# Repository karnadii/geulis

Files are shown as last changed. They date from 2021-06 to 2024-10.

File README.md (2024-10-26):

# Geulis
Wireless alice layout keyboard
# Images
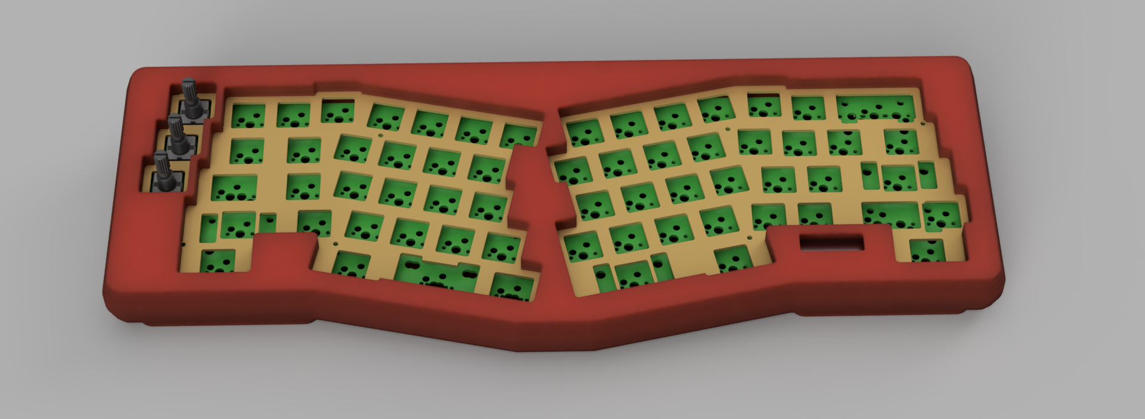
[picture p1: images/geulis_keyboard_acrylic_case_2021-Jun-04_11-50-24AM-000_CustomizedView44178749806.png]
PCB Front View


# Firmware
[https://github.com/karnadii/geulis_config_module](https://github.com/karnadii/geulis_config_module)

NOTE: My keyboard case is terrible. Make your own case or use someone else's. The RGB drains a lot of battery, but if you cut the power trace to the RGB, the battery life is amazing, thanks to ZMK. I haven't charged my keyboard in over half a year, and it still has more than 50% battery left.

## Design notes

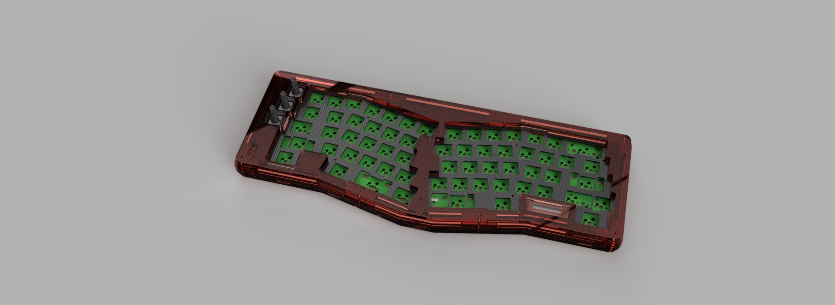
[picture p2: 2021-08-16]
images/geulis_acrylic_case_v3_screw_2021-Jul-15_01-08-26AM-000_CustomizedView15097228685.png

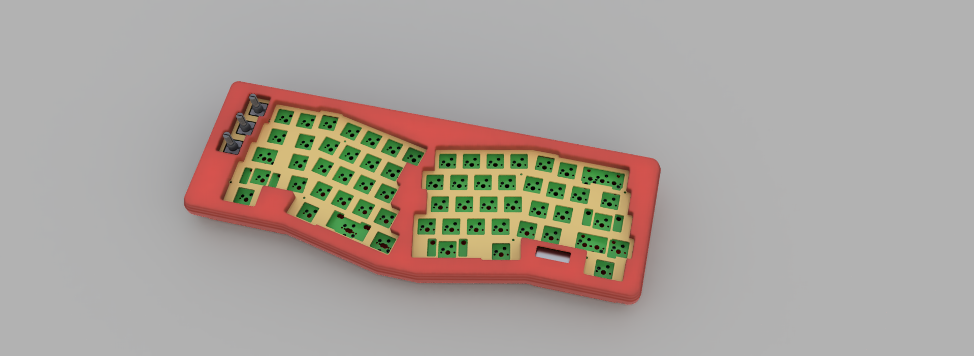
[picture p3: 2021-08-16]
images/c8df9fd2-e070-493f-910b-0edc783d997d.PNG

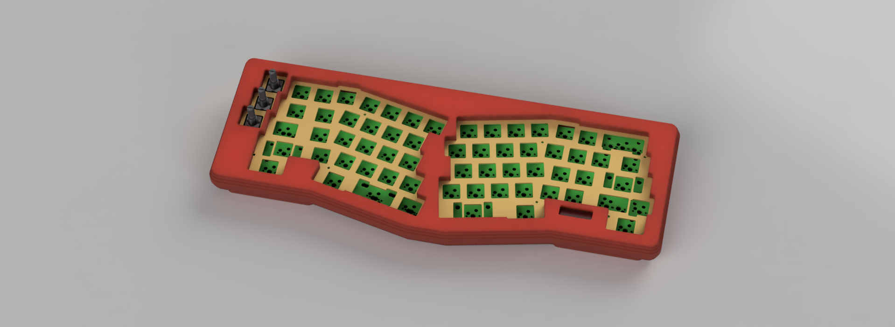
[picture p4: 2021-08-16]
images/geulis_keyboard_acrylic_case_2021-Jun-03_07-44-22PM-000_CustomizedView18685608333.png

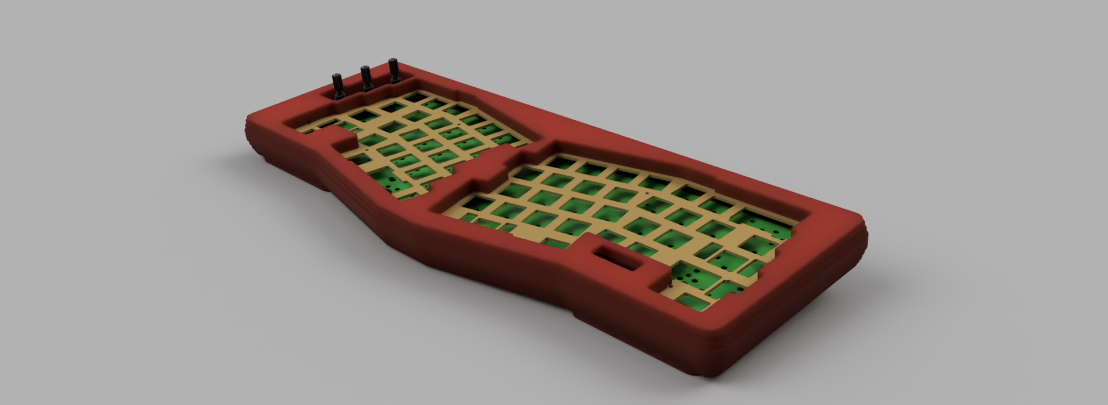
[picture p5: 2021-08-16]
images/geulis_keyboard_acrylic_case_2021-Jun-03_07-30-29PM-000_CustomizedView2518468134.png

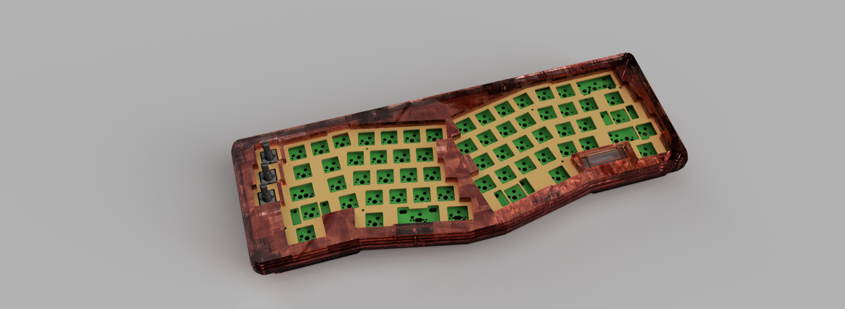
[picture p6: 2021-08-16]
images/6f7de3ee-63c1-44c7-aa9e-37ba1ee566a7.PNG

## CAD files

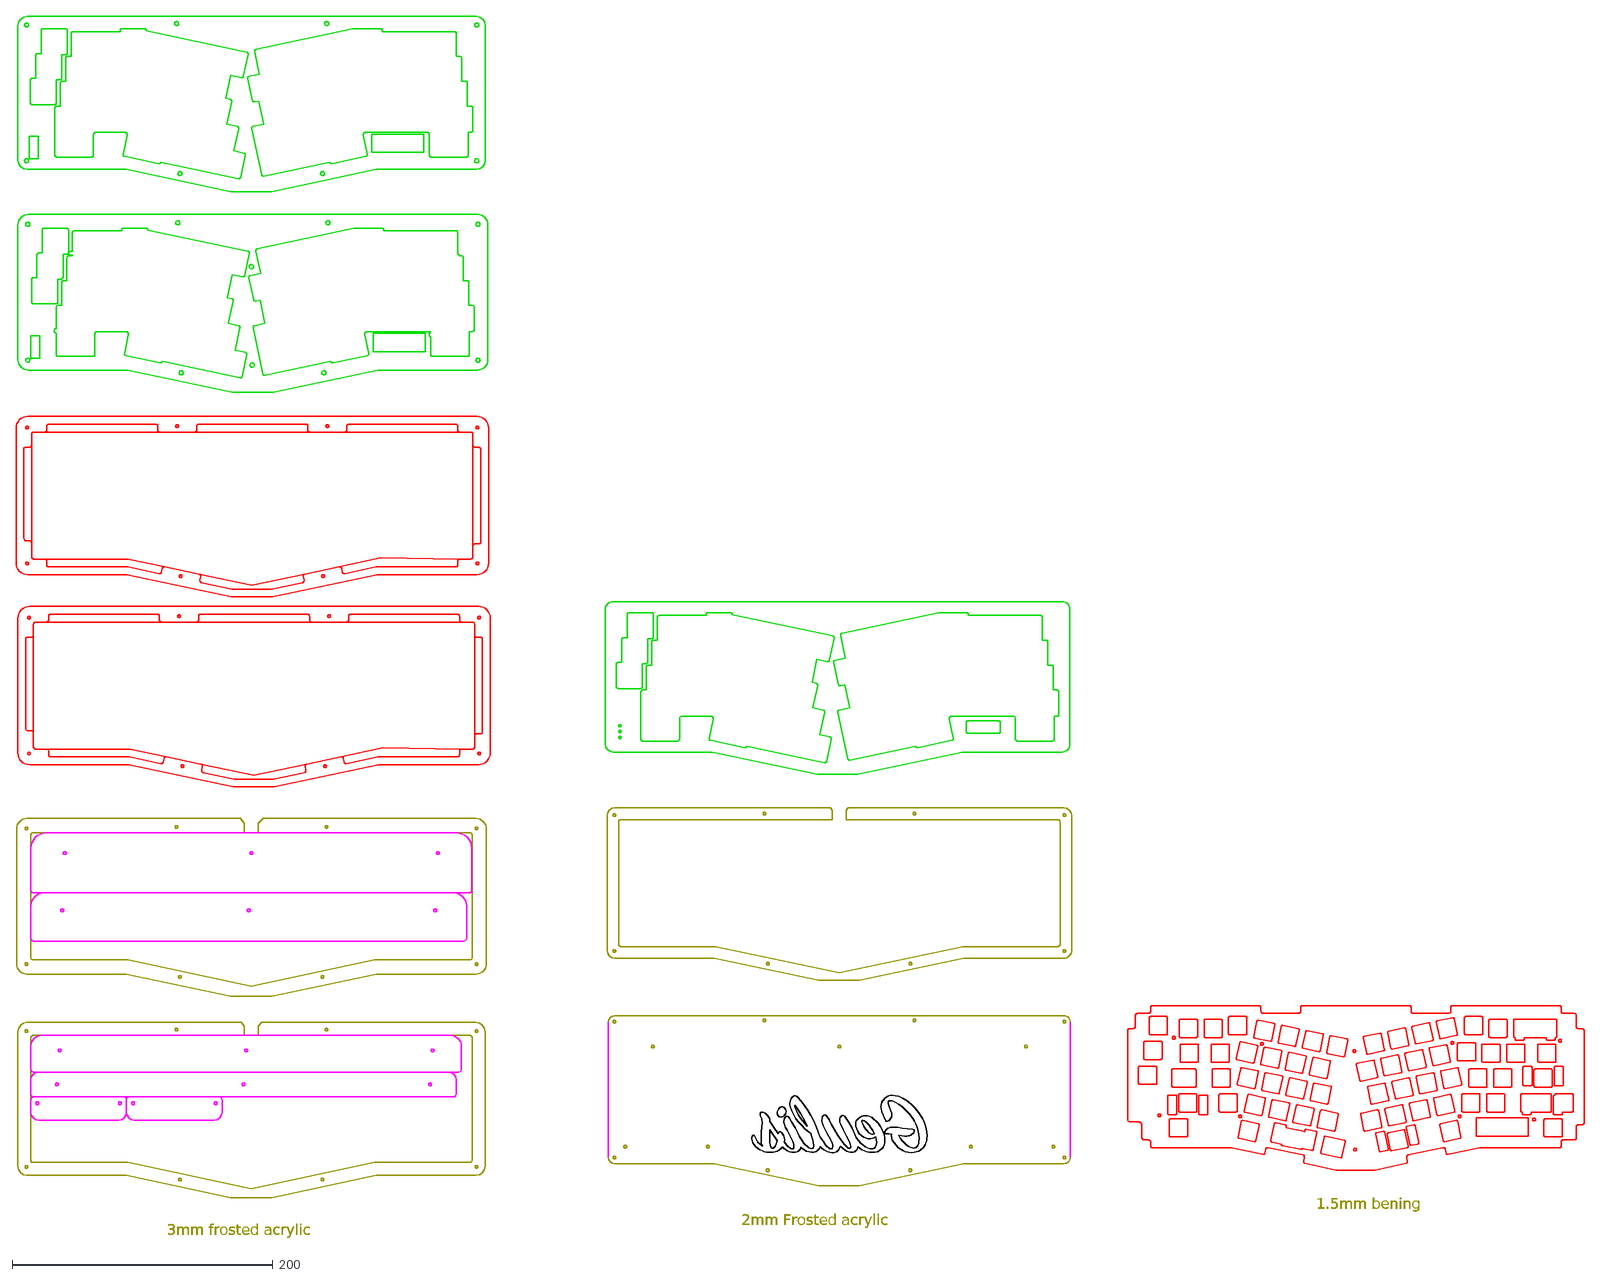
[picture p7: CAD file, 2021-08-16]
case/geulis_acrylic_case.dxf
3mm frosted acrylic
2mm Frosted acrylic
1.5mm bening

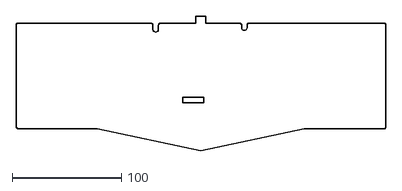
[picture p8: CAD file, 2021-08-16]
hardware/DXF/geulis-Edge_Cuts.dxf
337.2 x 122.6

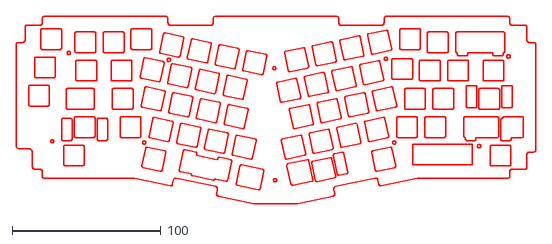
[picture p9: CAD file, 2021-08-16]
case/geulis plate.dxf
349.8 x 126.0

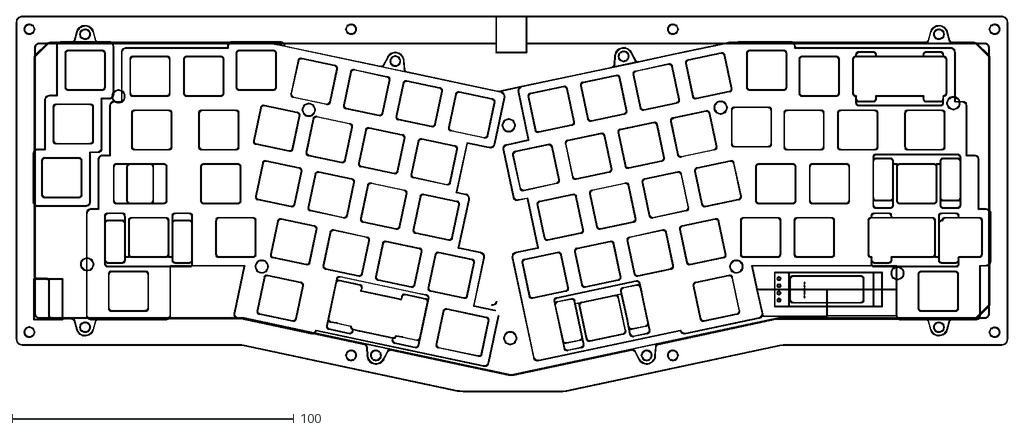
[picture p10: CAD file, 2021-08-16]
hardware/DXF/geulis-Cmts_User.dxf
351.4 x 133.1

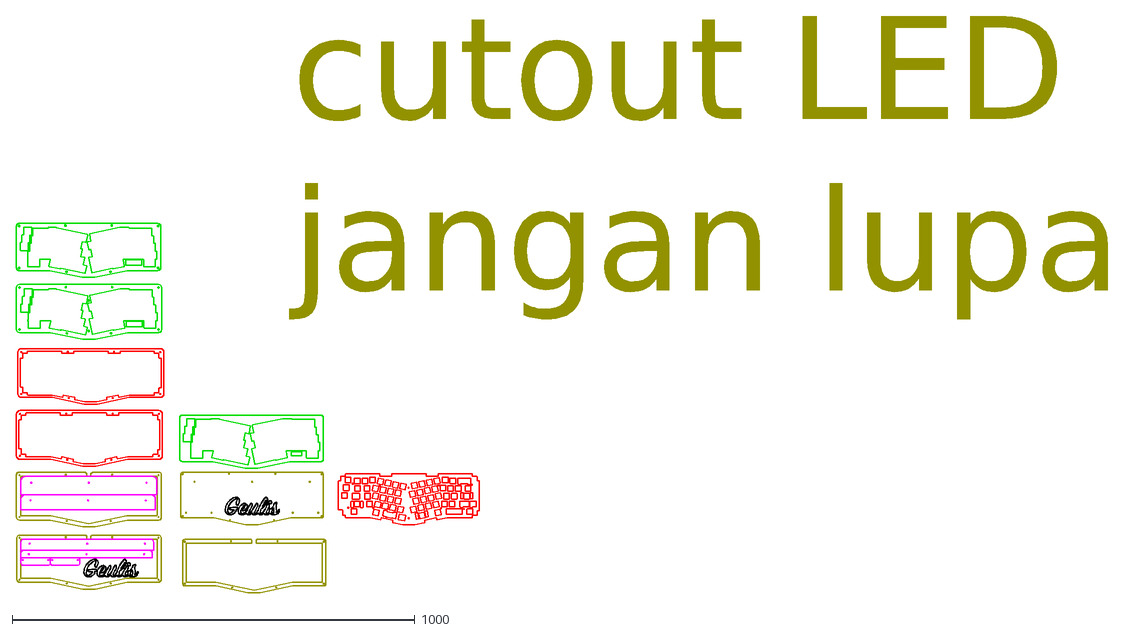
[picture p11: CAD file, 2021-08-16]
case/acrylic case outline.dxf
cutout LED
jangan lupa

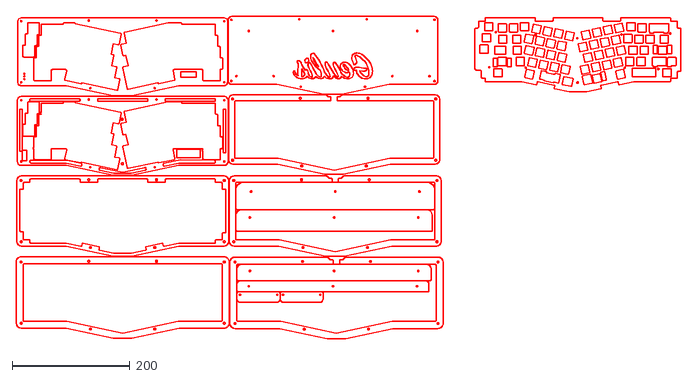
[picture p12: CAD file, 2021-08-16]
case/geulis_acrylic_case_v2.dxf
1129.5 x 547.1

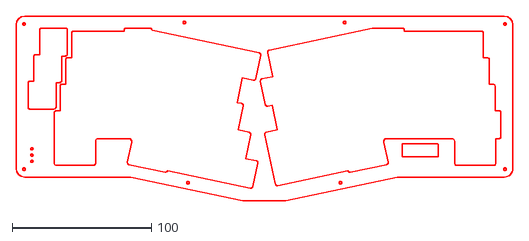
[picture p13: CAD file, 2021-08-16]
case/geulis acrylic top.dxf
356.2 x 132.4

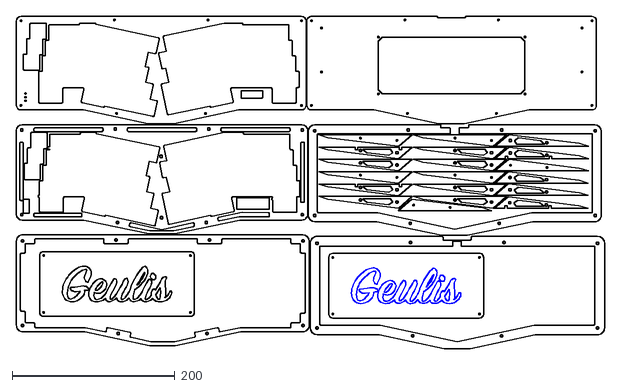
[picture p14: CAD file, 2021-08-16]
case/geulis_v5_3mm_frosted.dxf
723.5 x 409.1

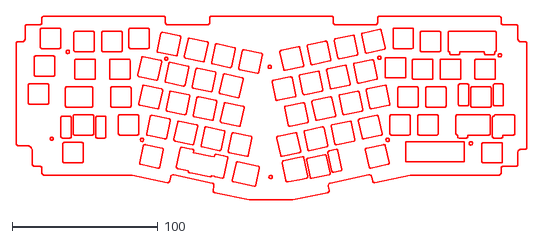
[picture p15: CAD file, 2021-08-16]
case/geulisv2_1.5mm.dxf
349.8 x 126.0

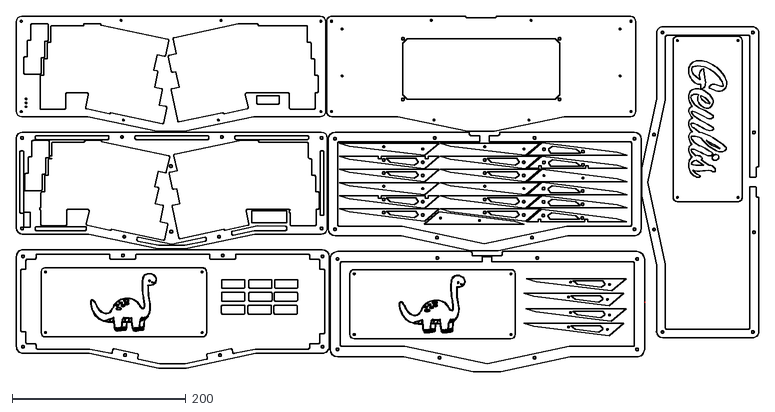
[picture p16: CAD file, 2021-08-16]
case/geulis_v5_3mm_hitam_trans.dxf
854.9 x 409.1

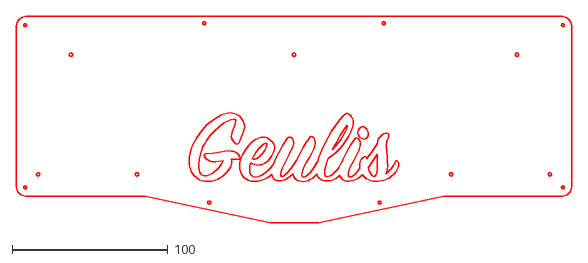
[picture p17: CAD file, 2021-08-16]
case/geulis acrylic bottom.dxf
356.2 x 132.4

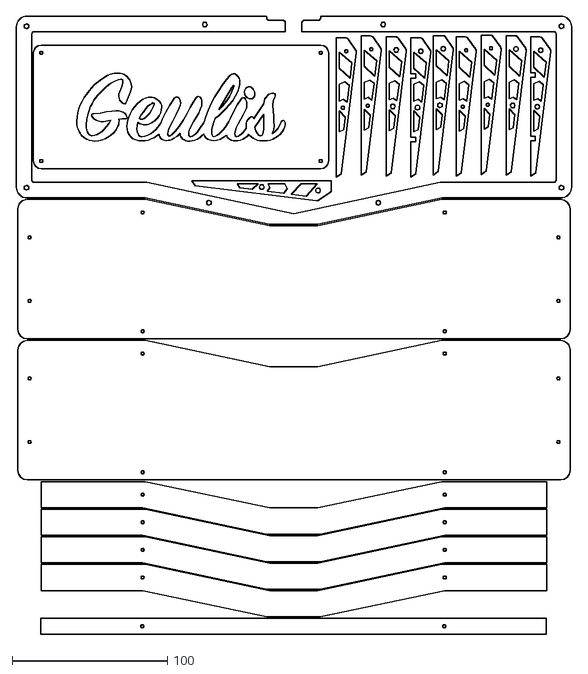
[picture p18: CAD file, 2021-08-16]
case/geulis_v5_3mm_Putih_susu_bening_satin.dxf
358.2 x 398.7

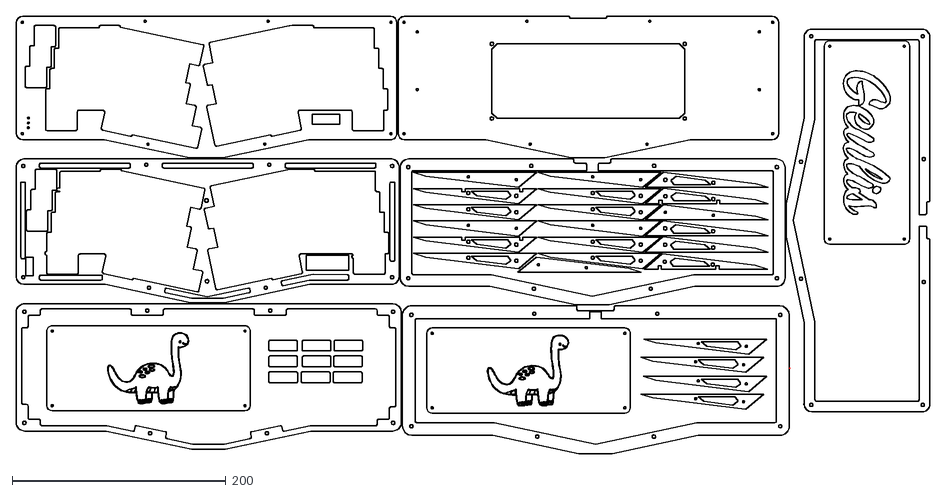
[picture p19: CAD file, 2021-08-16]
case/geulis_v5_3mm_hitam_transdparan.dxf
854.9 x 409.1

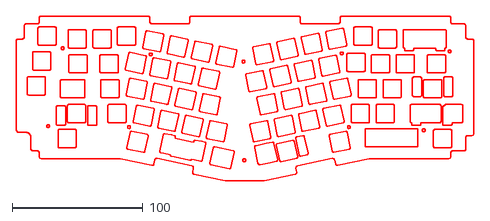
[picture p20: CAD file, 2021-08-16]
case/geulis_plate_1.5mm.dxf
349.8 x 126.0

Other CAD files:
case/Cheshire full Acrylic_te4st.dwg
case/plate.dwg
case/geulis_v5_3mm_hitam_transparan-browntosaurus.dwg
case/geulis_v3_1.5mm_bening.dxf
case/acrylic case outline.dwg
case/geulis plate.dwg
case/geulis_1.5mm_bening.dwg
case/geulis_1.5mm_bening.dxf
case/geulis_2mm_frosted.dwg
case/geulis_2mm_frosted.dxf
case/geulis_3mm_frosted.dwg
case/geulis_3mm_frosted.dxf
case/geulis_acrylic_case.dwg
case/geulis_acrylic_case_v2.dwg
case/geulis_acrylic_case_v2_screw.dwg
case/geulis_acrylic_case_v2_screw.dxf
case/geulis_acrylic_case_v2_screwless.dwg
case/geulis_plate_for_geulis_case.dwg
case/geulis_plate_for_geulis_case.dxf
case/geulis_v3_1.5mm_bening.dwg
case/geulis_v3_3mm_frosted.dwg
case/geulis_v4_3mm_frosted.dwg
case/geulis_v4_3mm_frosted.dxf
case/geulis_v5_1.5mm.dxf
case/geulis_v5_3mm_Putih_susu_bening_satin.dwg
case/geulis_v5_3mm_frosted.dwg
case/geulis_v5_3mm_merah_transparan.dwg
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

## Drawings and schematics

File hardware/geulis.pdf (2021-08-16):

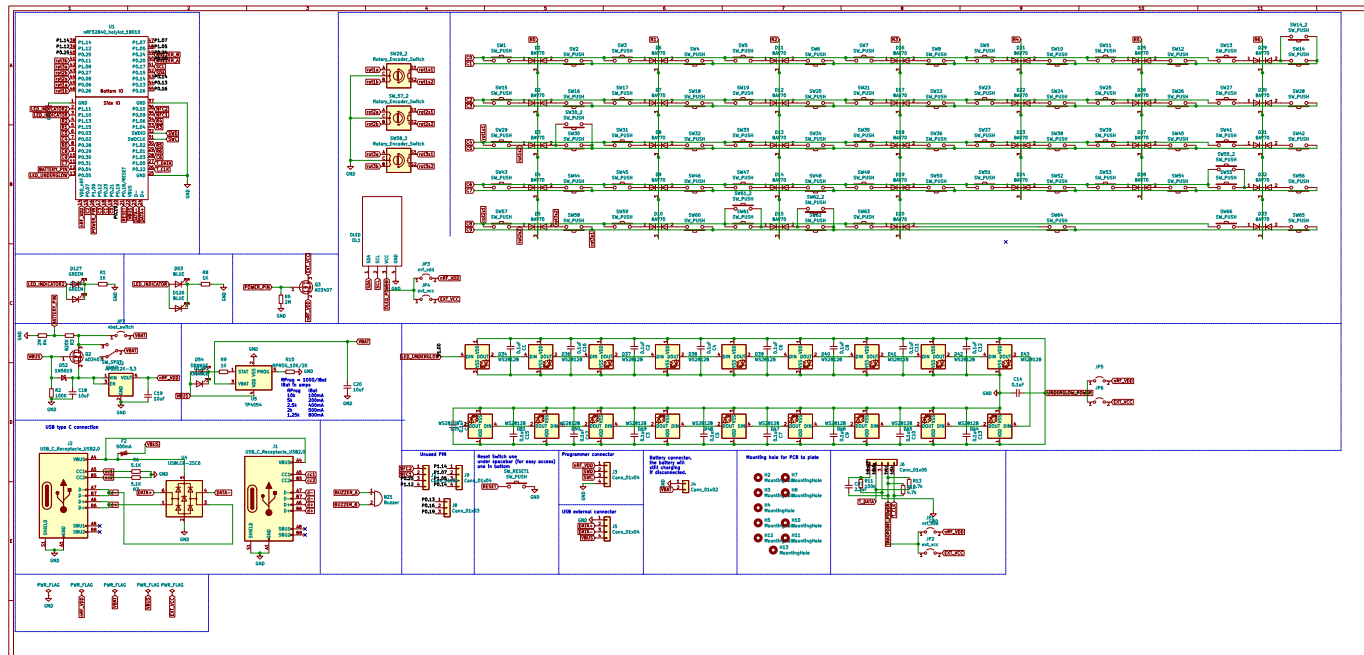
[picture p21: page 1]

if disconnected. Programmer connector USB external connector Reset Switch one under spacebar (for easy access) one in bottom

H13 MountingHole H12 MountingHole H11 MountingHole H10 MountingHole

File: geulis.sch Sheet: /

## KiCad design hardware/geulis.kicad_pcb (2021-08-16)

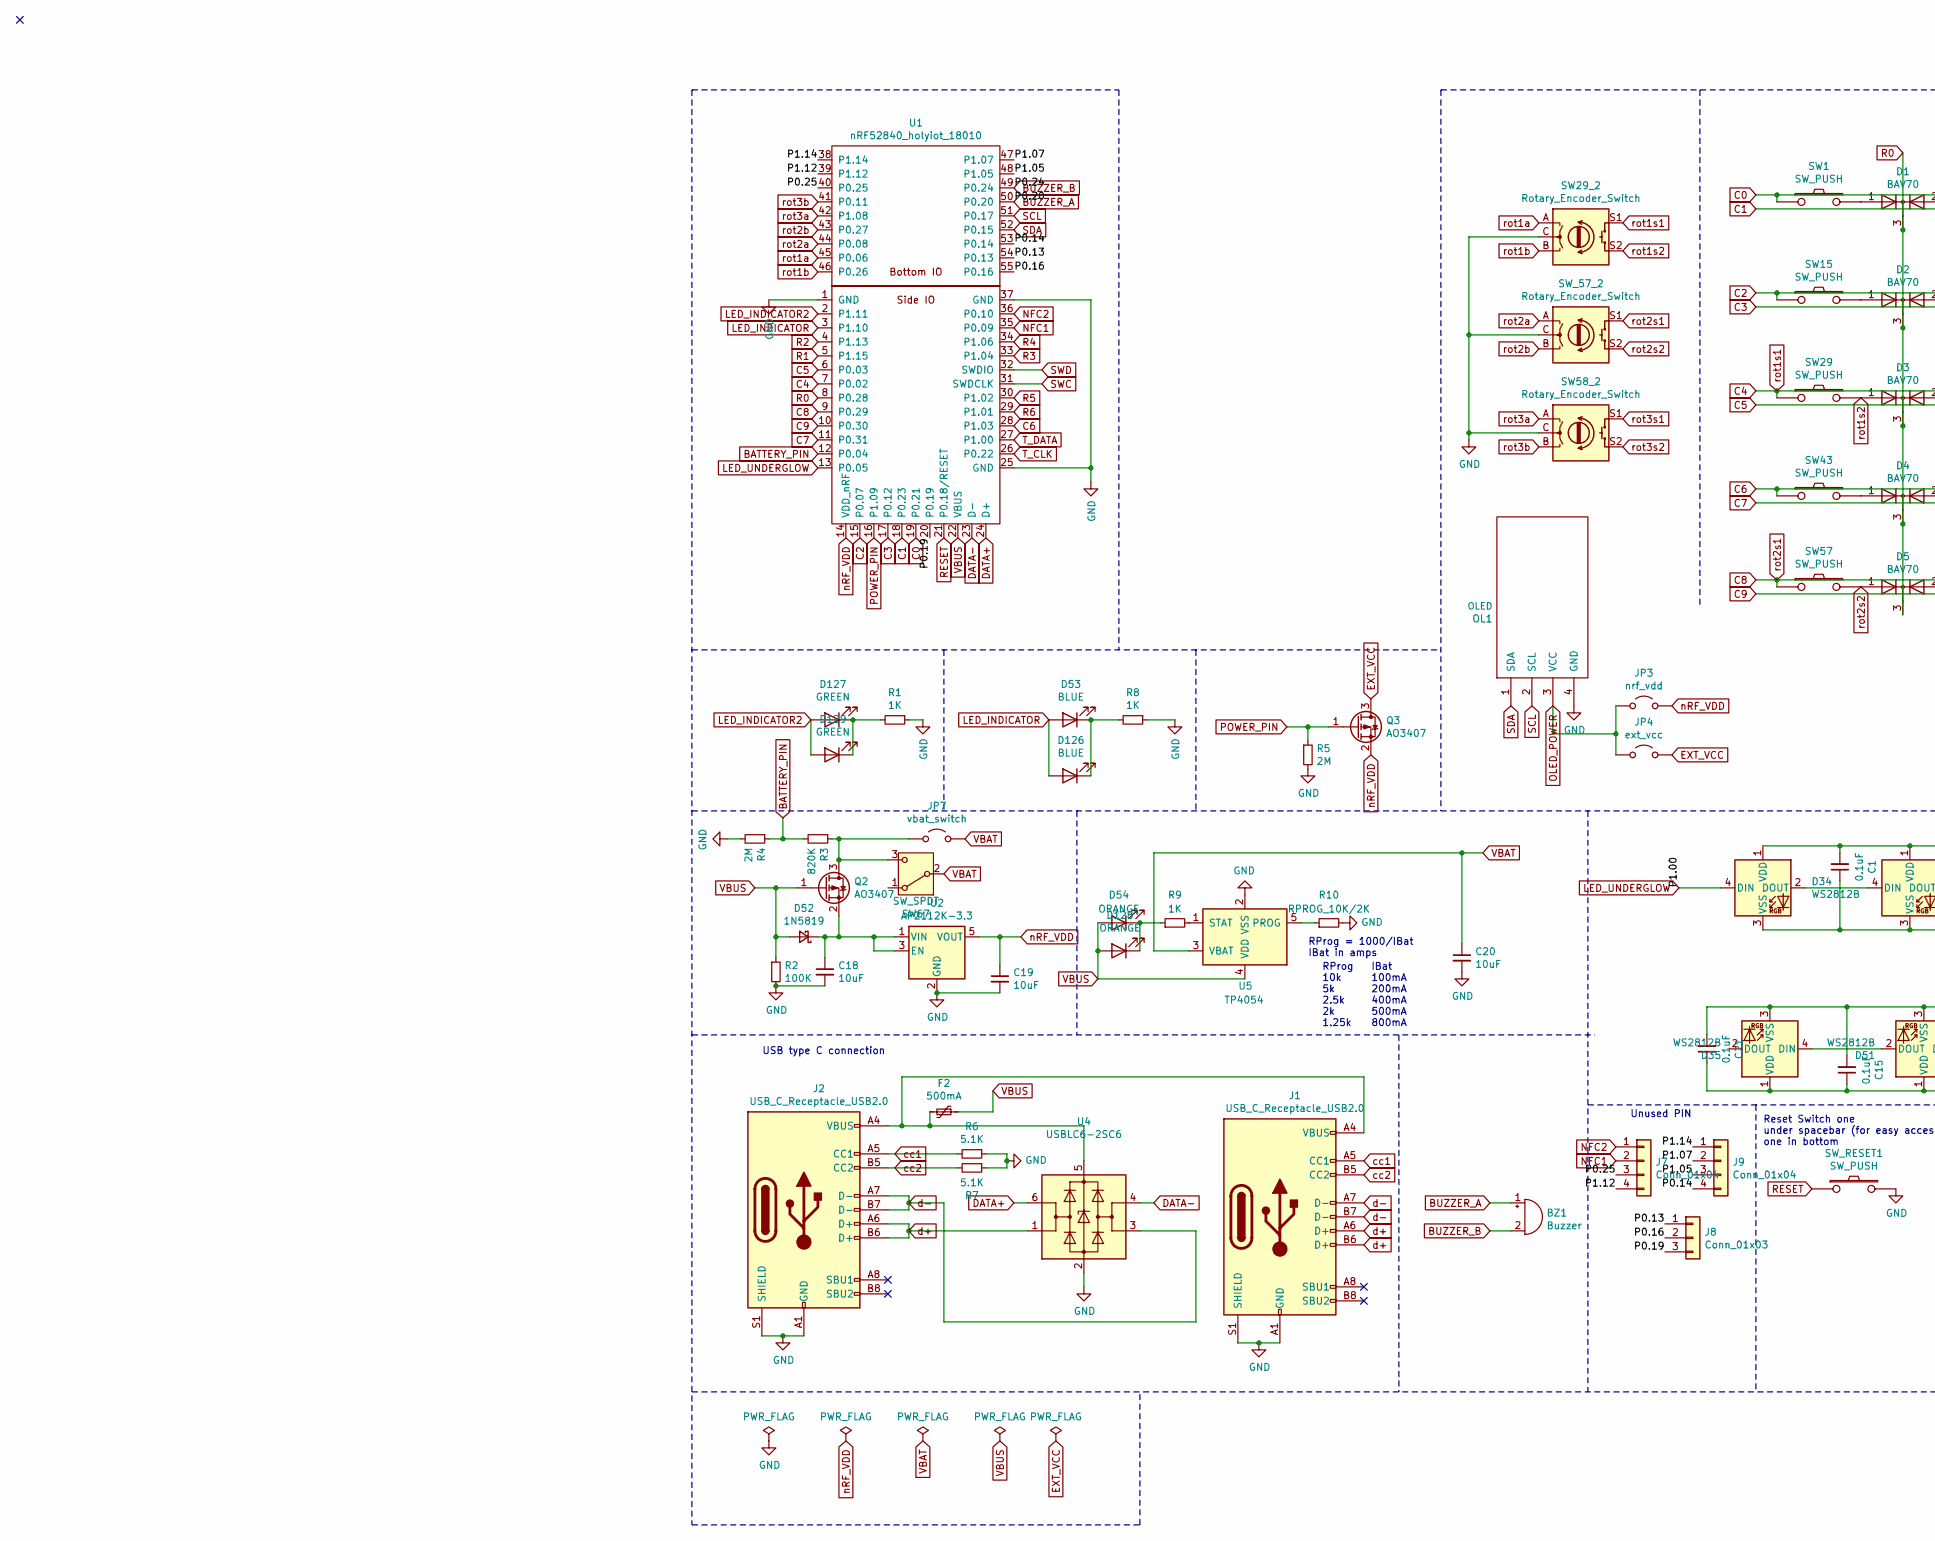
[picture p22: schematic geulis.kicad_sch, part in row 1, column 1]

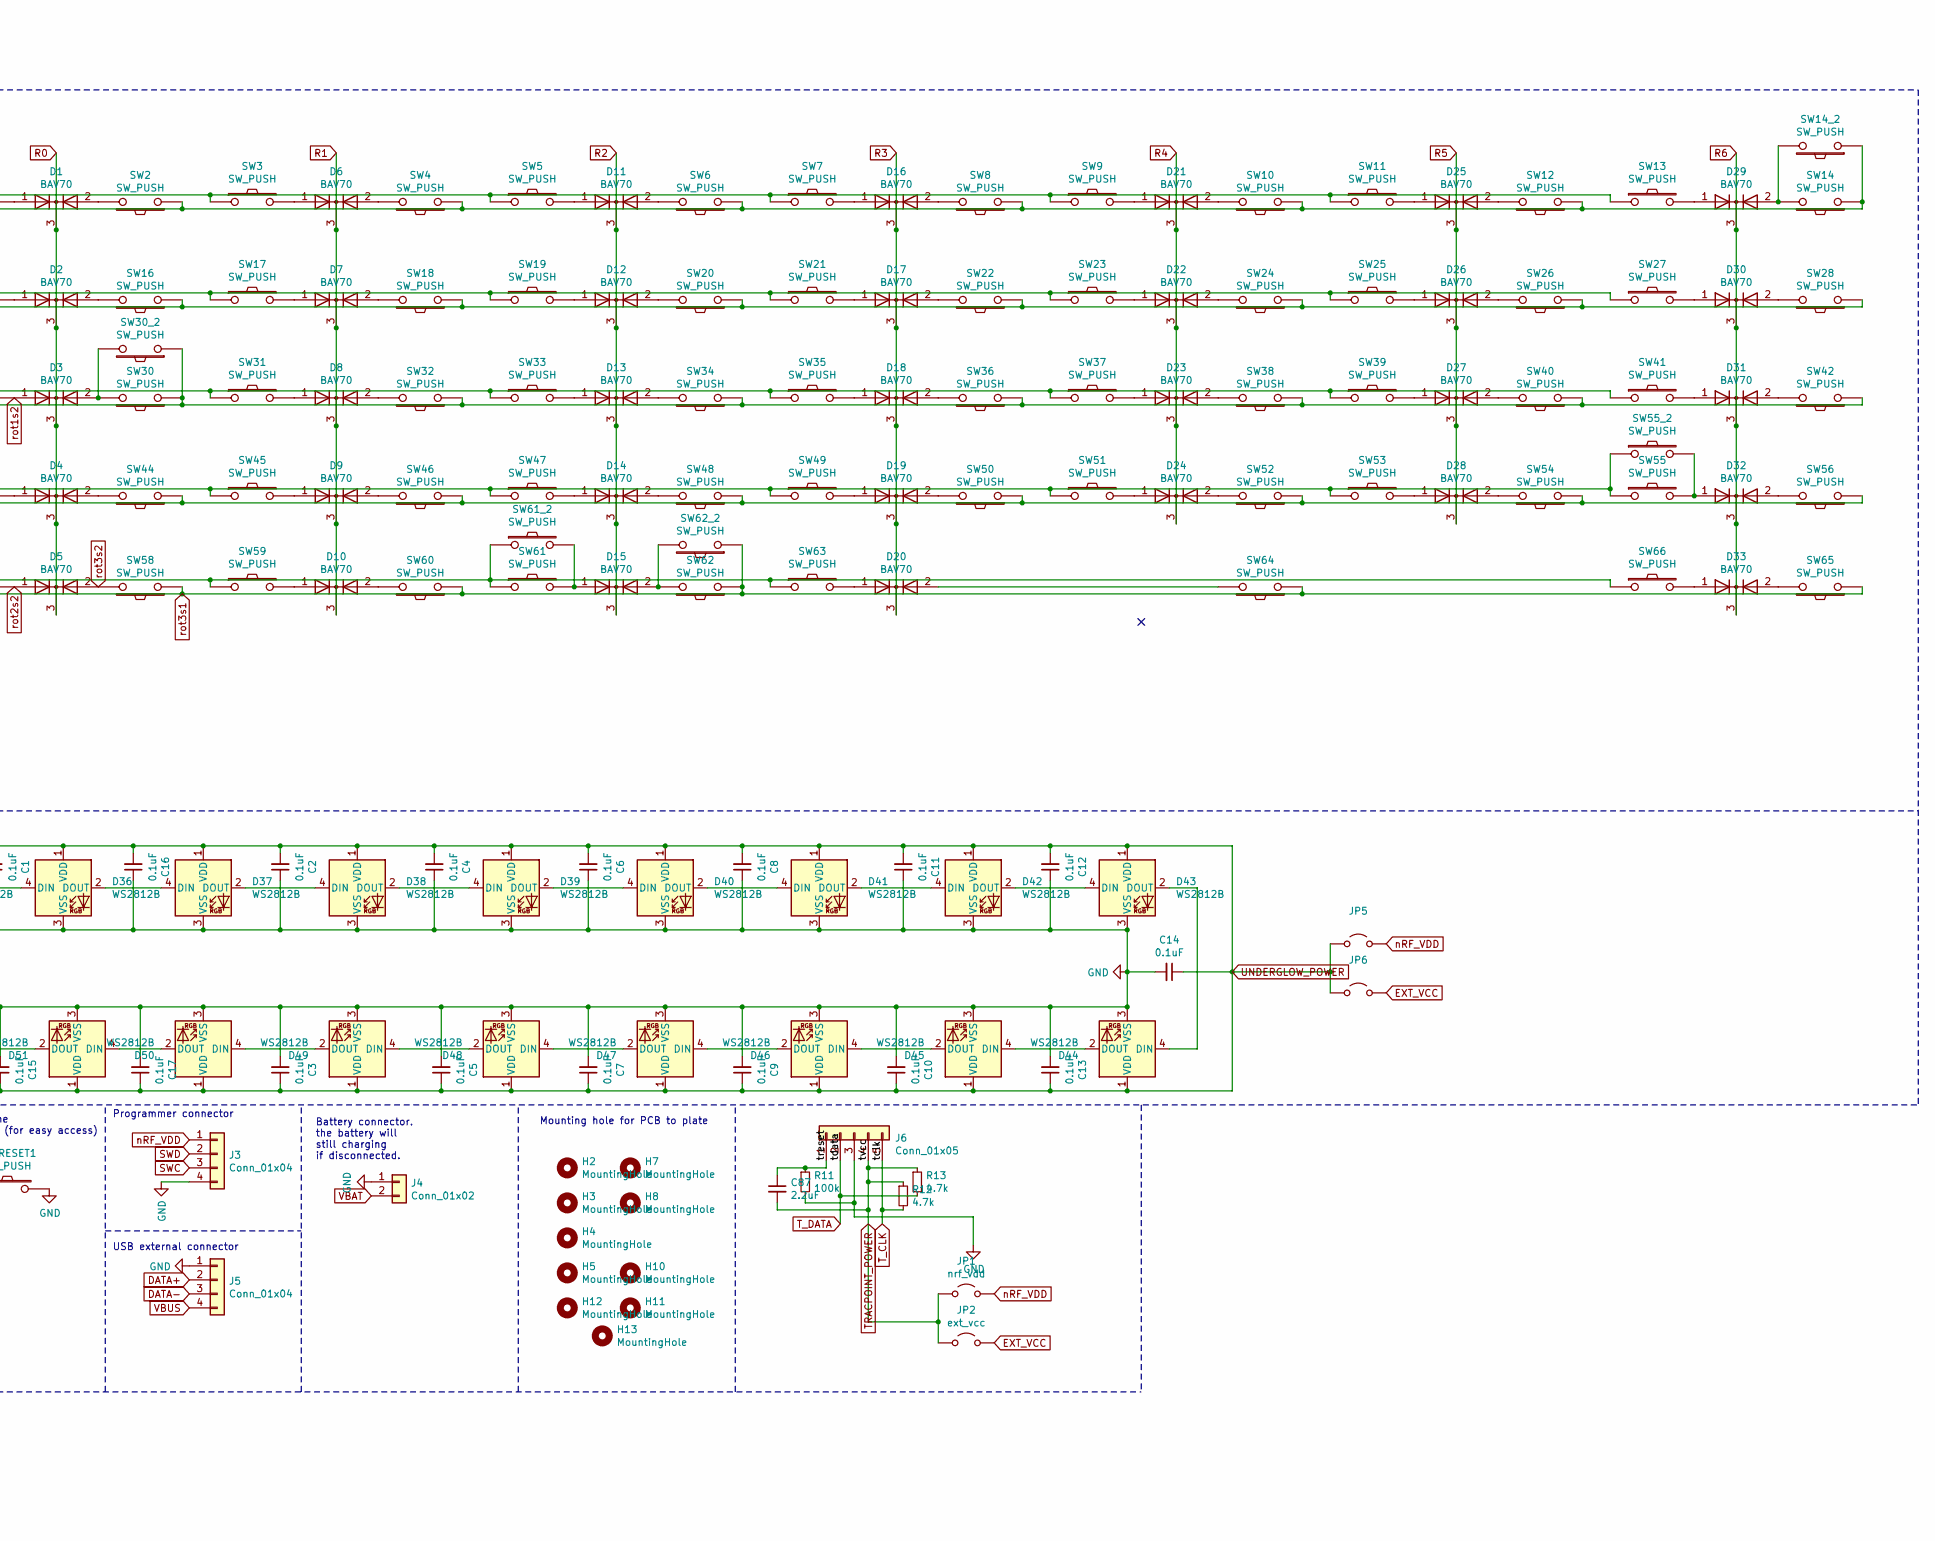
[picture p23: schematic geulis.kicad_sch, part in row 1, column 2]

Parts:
BZ1: Buzzer; PKLCS1212E2000-R1
C1, C2, C3, C4, C5, C6, C7, C8, C9, C10, C11, C12, C13, C14, C15, C16, C17, C21: 0.1uF; C_0805_2012Metric_Pad1.18x1.45mm_HandSolder; LCSC C49678
C18, C19, C20: 10uF; C_0805_2012Metric_Pad1.18x1.45mm_HandSolder; LCSC C15850
C87: 2.2uF; C_0805_2012Metric_Pad1.18x1.45mm_HandSolder
D1, D2, D3, D4, D5, D6, D7, D8, D9, D10, D11, D12, D13, D14, D15, D16, D17, D18, D19, D20, D21, D22, D23, D24, D25, D26, D27, D28, D29, D30, D31, D32, D33: BAV70; SOT-23
D34, D35, D36, D37, D38, D39, D40, D41, D42, D43, D44, D45, D46, D47, D48, D49, D50, D51: WS2812B; WS2812B_data-bridgeable; LCSC C114586
D52: 1N5819; D_SOD-123; LCSC C169540
D53: BLUE; LED_0603_1608Metric_Pad1.05x0.95mm_HandSolder; LCSC C375446
D54: ORANGE; LED_0603_1608Metric_Pad1.05x0.95mm_HandSolder; LCSC C375450
D126: BLUE; LED_D3.0mm
D127: GREEN; LED_D3.0mm
D128: ORANGE; LED_D3.0mm
D129: GREEN; LED_0603_1608Metric_Pad1.05x0.95mm_HandSolder
F2: 500mA; Fuse_0805_2012Metric_Pad1.15x1.40mm_HandSolder; LCSC C261942
H2, H3, H4, H5, H7, H8, H10, H11, H12, H13: MountingHole; MountingHole_2.2mm_M2_Pad
J1, J2: USB_C_Receptacle_USB2.0; USB_C_Receptacle_HRO_TYPE-C-31-M-12; LCSC C165948
J3: Conn_01x04; connector_swd
J4: Conn_01x02; JST_XH_S2B-XH-A-1_1x02_P2.50mm_Horizontal; LCSC C157931
J5: Conn_01x04; connector_usb
J6: Conn_01x05; PinHeader_1x05_P2.54mm_Vertical
J7, J9: Conn_01x04; PinHeader_1x04_P2.00mm_Vertical
J8: Conn_01x03; PinHeader_1x03_P2.00mm_Vertical
JP1, JP3: nrf_vdd; Jumper
JP2, JP4: ext_vcc; Jumper
JP5, JP6: Jumper_2_Open; Jumper
JP7: vbat_switch; Jumper
OL1: OLED
Q2, Q3: AO3407; TSOT-23; LCSC C693136
R1, R8, R9: 1K; R_0603_1608Metric_Pad0.98x0.95mm_HandSolder; LCSC C21190
R2: 100K; R_0603_1608Metric_Pad0.98x0.95mm_HandSolder; LCSC C25803
R3: 820K; R_0603_1608Metric_Pad0.98x0.95mm_HandSolder; LCSC C23252
R4, R5: 2M; R_0603_1608Metric_Pad0.98x0.95mm_HandSolder; LCSC C22976
R6, R7: 5.1K; R_0603_1608Metric_Pad0.98x0.95mm_HandSolder; LCSC C23186
R10: RPROG_10K/2K; R_0603_1608Metric_Pad0.98x0.95mm_HandSolder; LCSC C22975
R11: 100k; R_0603_1608Metric_Pad0.98x0.95mm_HandSolder
R12, R13: 4.7k; R_0603_1608Metric_Pad0.98x0.95mm_HandSolder
SW1, SW2, SW3, SW4, SW5, SW6, SW7, SW8, SW9, SW10, SW11, SW12, SW13, SW14_2, SW16, SW17, SW18, SW19, SW20, SW21, SW22, SW23, SW24, SW25, SW26, SW27, SW29, SW31, SW32, SW33, SW34, SW35, SW36, SW37, SW38, SW39, SW40, SW41, SW44, SW45, SW46, SW47, SW48, SW49, SW50, SW51, SW52, SW53, SW54, SW56, SW57, SW58, SW62_2, SW66: SW_PUSH; MXOnly-1U-Hotswap
SW14: SW_PUSH; MXOnly-2U-Hotswap
SW15, SW28, SW59, SW60, SW64, SW65: SW_PUSH; MXOnly-1.5U-Hotswap
SW29_2, SW58_2: Rotary_Encoder_Switch; RotaryEncoder_Alps_EC11E-Switch_Vertical_H20mm
SW30, SW55: SW_PUSH; MXOnly-1.75U-Hotswap
SW30_2, SW62: SW_PUSH; MXOnly-1.25U-Hotswap
SW42: SW_PUSH; MXOnly-2.25U-Hotswap-ReversedStabilizers
SW43, SW61_2: SW_PUSH; MXOnly-2.25U-Hotswap
SW55_2, SW63: SW_PUSH; MXOnly-2.75U-Hotswap-ReversedStabilizers
SW61: SW_PUSH; MXOnly-2U-Hotswap-ReversedStabilizers
SW67: SW_SPDT; SW_SPDT_PCM12; LCSC C221841
SW_57_2: Rotary_Encoder_Switch; RotaryEncoder_Alps_EC11E-Switch_Vertical_H20mm
SW_RESET1: SW_PUSH; SW_SPST_TL3342; LCSC C318884
U1: nRF52840_holyiot_18010
U2: AP2112K-3.3; SOT-23-5; LCSC C51118
U4: USBLC6-2SC6; SOT-23-6; LCSC C558442
U5: TP4054; SOT-23-5; LCSC C32574

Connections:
/P0.13: J8.1, U1.54 (P0.13)
/P0.14: J9.4, U1.53 (P0.14)
/P0.16: J8.2, U1.55 (P0.16)
/P0.19: J8.3, U1.20 (P0.19)
/P0.25: J7.3, U1.40 (P0.25)
/P1.05: J9.3, U1.48 (P1.05)
/P1.07: J9.2, U1.47 (P1.07)
/P1.12: J7.4, U1.39 (P1.12)
/P1.14: J9.1, U1.38 (P1.14)
/treset: C87.1, J6.1, R11.1
BATTERY_PIN: R3.2, R4.1, U1.12 (P0.04)
BUZZER_A: BZ1.1 (-), U1.50 (P0.20)
BUZZER_B: BZ1.2 (+), U1.49 (P0.24)
C0: SW1.1, SW3.1, SW5.1, SW7.1, SW9.1, SW11.1, SW13.1, U1.19 (P0.21)
C1: SW2.1, SW4.1, SW6.1, SW8.1, SW10.1, SW12.1, SW14.1, SW14_2.1, U1.18 (P0.23)
C2: SW15.1, SW17.1, SW19.1, SW21.1, SW23.1, SW25.1, SW27.1, U1.15 (P0.07)
C3: SW16.1, SW18.1, SW20.1, SW22.1, SW24.1, SW26.1, SW28.1, U1.17 (P0.12)
C4: SW29.1, SW29_2.S1, SW31.1, SW33.1, SW35.1, SW37.1, SW39.1, SW41.1, U1.7 (P0.02)
C5: SW30.1, SW30_2.1, SW32.1, SW34.1, SW36.1, SW38.1, SW40.1, SW42.1, U1.6 (P0.03)
C6: SW43.1, SW45.1, SW47.1, SW49.1, SW51.1, SW53.1, SW55.1, SW55_2.1, U1.28 (P1.03)
C7: SW44.1, SW46.1, SW48.1, SW50.1, SW52.1, SW54.1, SW56.1, U1.11 (P0.31)
C8: SW57.1, SW59.1, SW61.1, SW61_2.1, SW63.1, SW66.1, SW_57_2.S1, U1.9 (P0.29)
C9: SW58.1, SW58_2.S1, SW60.1, SW62.1, SW62_2.1, SW64.1, SW65.1, U1.10 (P0.30)
DATA+: J5.2, U1.24 (D+), U4.6 (I/O1)
DATA-: J5.3, U1.23 (D-), U4.4 (I/O2)
EXT_VCC: JP2.2 (B), JP4.2 (B), JP6.2 (B), Q3.3 (D)
GND: C1.1, C2.1, C3.2, C4.1, C5.2, C6.1, C7.2, C8.1, C9.2, C10.2, C11.1, C12.1, C13.2, C14.2, C15.2, C16.1, C17.2, C18.2, C19.2, C20.2, C21.2, D34.3 (VSS), D35.3 (VSS), D36.3 (VSS), D37.3 (VSS), D38.3 (VSS), D39.3 (VSS), D40.3 (VSS), D41.3 (VSS), D42.3 (VSS), D43.3 (VSS), D44.3 (VSS), D45.3 (VSS), D46.3 (VSS), D47.3 (VSS), D48.3 (VSS), D49.3 (VSS), D50.3 (VSS), D51.3 (VSS), J1.A1 (GND), J1.A12 (GND), J1.B1 (GND), J1.B12 (GND), J1.S1 (SHIELD), J2.A1 (GND), J2.A12 (GND), J2.B1 (GND), J2.B12 (GND), J2.S1 (SHIELD), J3.4, J4.1, J5.1, J6.3, OL1.4 (GND), R1.1, R2.2, R4.2, R5.2, R6.1, R7.1, R8.1, R10.2, R11.2, SW29_2.C, SW58_2.C, SW_57_2.C, SW_RESET1.2, U1.1 (GND), U1.25 (GND), U1.37 (GND), U2.2 (GND), U4.2 (GND), U5.2 (VSS)
LED_INDICATOR: D53.2 (A), D126.2 (A), U1.3 (P1.10)
LED_INDICATOR2: D127.2 (A), D129.2 (A), U1.2 (P1.11)
LED_UNDERGLOW: D34.4 (DIN), U1.13 (P0.05)
NFC1: J7.2, U1.35 (P0.09)
NFC2: J7.1, U1.36 (P0.10)
unnamed: C18.1, D52.1 (K), Q2.2 (S), U2.1 (VIN), U2.3 (EN)
unnamed: D1.1 (A), SW1.2
unnamed: D1.2 (A), SW2.2
unnamed: D2.1 (A), SW15.2
unnamed: D2.2 (A), SW16.2
unnamed: D3.2 (A), SW30.2, SW30_2.2
unnamed: D4.1 (A), SW43.2
unnamed: D4.2 (A), SW44.2
unnamed: D6.1 (A), SW3.2
unnamed: D6.2 (A), SW4.2
unnamed: D7.1 (A), SW17.2
unnamed: D7.2 (A), SW18.2
unnamed: D8.1 (A), SW31.2
unnamed: D8.2 (A), SW32.2
unnamed: D9.1 (A), SW45.2
unnamed: D9.2 (A), SW46.2
unnamed: D10.1 (A), SW59.2
unnamed: D10.2 (A), SW60.2
unnamed: D11.1 (A), SW5.2
unnamed: D11.2 (A), SW6.2
unnamed: D12.1 (A), SW19.2
unnamed: D12.2 (A), SW20.2
unnamed: D13.1 (A), SW33.2
unnamed: D13.2 (A), SW34.2
unnamed: D14.1 (A), SW47.2
unnamed: D14.2 (A), SW48.2
unnamed: D15.1 (A), SW61.2, SW61_2.2
unnamed: D15.2 (A), SW62.2, SW62_2.2
unnamed: D16.1 (A), SW7.2
unnamed: D16.2 (A), SW8.2
unnamed: D17.1 (A), SW21.2
unnamed: D17.2 (A), SW22.2
unnamed: D18.1 (A), SW35.2
unnamed: D18.2 (A), SW36.2
unnamed: D19.1 (A), SW49.2
unnamed: D19.2 (A), SW50.2
unnamed: D20.1 (A), SW63.2
unnamed: D20.2 (A), SW64.2
unnamed: D21.1 (A), SW9.2
unnamed: D21.2 (A), SW10.2
unnamed: D22.1 (A), SW23.2
unnamed: D22.2 (A), SW24.2
unnamed: D23.1 (A), SW37.2
unnamed: D23.2 (A), SW38.2
unnamed: D24.1 (A), SW51.2
unnamed: D24.2 (A), SW52.2
unnamed: D25.1 (A), SW11.2
unnamed: D25.2 (A), SW12.2
unnamed: D26.1 (A), SW25.2
unnamed: D26.2 (A), SW26.2
unnamed: D27.1 (A), SW39.2
unnamed: D27.2 (A), SW40.2
unnamed: D28.1 (A), SW53.2
unnamed: D28.2 (A), SW54.2
unnamed: D29.1 (A), SW13.2
unnamed: D29.2 (A), SW14.2, SW14_2.2
unnamed: D30.1 (A), SW27.2
unnamed: D30.2 (A), SW28.2
unnamed: D31.1 (A), SW41.2
unnamed: D31.2 (A), SW42.2
unnamed: D32.1 (A), SW55.2, SW55_2.2
unnamed: D32.2 (A), SW56.2
unnamed: D33.1 (A), SW66.2
unnamed: D33.2 (A), SW65.2
unnamed: D34.2 (DOUT), D36.4 (DIN)
unnamed: D35.4 (DIN), D51.2 (DOUT)
unnamed: D36.2 (DOUT), D37.4 (DIN)
unnamed: D37.2 (DOUT), D38.4 (DIN)
unnamed: D38.2 (DOUT), D39.4 (DIN)
unnamed: D39.2 (DOUT), D40.4 (DIN)
unnamed: D40.2 (DOUT), D41.4 (DIN)
unnamed: D41.2 (DOUT), D42.4 (DIN)
unnamed: D42.2 (DOUT), D43.4 (DIN)
unnamed: D43.2 (DOUT), D44.4 (DIN)
unnamed: D44.2 (DOUT), D45.4 (DIN)
unnamed: D45.2 (DOUT), D46.4 (DIN)
unnamed: D46.2 (DOUT), D47.4 (DIN)
unnamed: D47.2 (DOUT), D48.4 (DIN)
unnamed: D48.2 (DOUT), D49.4 (DIN)
unnamed: D49.2 (DOUT), D50.4 (DIN)
unnamed: D50.2 (DOUT), D51.4 (DIN)
unnamed: D53.1 (K), D126.1 (K), R8.2
unnamed: D127.1 (K), D129.1 (K), R1.2
unnamed: D54.1 (K), D128.1 (K), R9.1
unnamed: F2.2, J1.A4 (VBUS), J1.A9 (VBUS), J1.B4 (VBUS), J1.B9 (VBUS), J2.A4 (VBUS), J2.A9 (VBUS), J2.B4 (VBUS), J2.B9 (VBUS), U4.5 (VBUS)
unnamed: JP7.1 (A), Q2.3 (D), R3.1, SW67.3 (C)
unnamed: R9.2, U5.1 (STAT)
unnamed: R10.1, U5.5 (PROG)
OLED_POWER: JP3.1 (A), JP4.1 (A), OL1.3 (VCC)
POWER_PIN: Q3.1 (G), R5.1, U1.16 (P1.09)
R0: D1.3 (K), D2.3 (K), D3.3 (K), D4.3 (K), D5.3 (K), U1.8 (P0.28)
R1: D6.3 (K), D7.3 (K), D8.3 (K), D9.3 (K), D10.3 (K), U1.5 (P1.15)
R2: D11.3 (K), D12.3 (K), D13.3 (K), D14.3 (K), D15.3 (K), U1.4 (P1.13)
R3: D16.3 (K), D17.3 (K), D18.3 (K), D19.3 (K), D20.3 (K), U1.33 (P1.04)
R4: D21.3 (K), D22.3 (K), D23.3 (K), D24.3 (K), U1.34 (P1.06)
R5: D25.3 (K), D26.3 (K), D27.3 (K), D28.3 (K), U1.30 (P1.02)
R6: D29.3 (K), D30.3 (K), D31.3 (K), D32.3 (K), D33.3 (K), U1.29 (P1.01)
RESET: SW_RESET1.1, U1.21 (P0.18/RESET)
SCL: OL1.2 (SCL), U1.51 (P0.17)
SDA: OL1.1 (SDA), U1.52 (P0.15)
SWC: J3.3, U1.31 (SWDCLK)
SWD: J3.2, U1.32 (SWDIO)
TRACPOINT_POWER: C87.2, J6.4, JP1.1 (A), JP2.1 (A), R12.1, R13.1
T_CLK: J6.5, R12.2, U1.26 (P0.22)
T_DATA: J6.2, R13.2, U1.27 (P1.00)
UNDERGLOW_POWER: C1.2, C2.2, C3.1, C4.2, C5.1, C6.2, C7.1, C8.2, C9.1, C10.1, C11.2, C12.2, C13.1, C14.1, C15.1, C16.2, C17.1, C21.1, D34.1 (VDD), D35.1 (VDD), D36.1 (VDD), D37.1 (VDD), D38.1 (VDD), D39.1 (VDD), D40.1 (VDD), D41.1 (VDD), D42.1 (VDD), D43.1 (VDD), D44.1 (VDD), D45.1 (VDD), D46.1 (VDD), D47.1 (VDD), D48.1 (VDD), D49.1 (VDD), D50.1 (VDD), D51.1 (VDD), JP5.1 (A), JP6.1 (A)
VBAT: C20.1, J4.2, JP7.2 (B), SW67.2 (B), U5.3 (VBAT)
VBUS: D52.2 (A), D54.2 (A), D128.2 (A), F2.1, J5.4, Q2.1 (G), R2.1, U1.22 (VBUS), U5.4 (VDD)
cc1: J1.A5 (CC1), J2.A5 (CC1), R6.2
cc2: J1.B5 (CC2), J2.B5 (CC2), R7.2
d+: J1.A6 (D+), J1.B6 (D+), J2.A6 (D+), J2.B6 (D+), U4.1 (I/O1)
d-: J1.A7 (D-), J1.B7 (D-), J2.A7 (D-), J2.B7 (D-), U4.3 (I/O2)
nRF_VDD: C19.1, J3.1, JP1.2 (B), JP3.2 (B), JP5.2 (B), Q3.2 (S), U1.14 (VDD_nRF), U2.5 (VOUT)
rot1a: SW29_2.A, U1.45 (P0.06)
rot1b: SW29_2.B, U1.46 (P0.26)
rot1s2: D3.1 (A), SW29.2, SW29_2.S2
rot2a: SW_57_2.A, U1.44 (P0.08)
rot2b: SW_57_2.B, U1.43 (P0.27)
rot2s2: D5.1 (A), SW57.2, SW_57_2.S2
rot3a: SW58_2.A, U1.42 (P1.08)
rot3b: SW58_2.B, U1.41 (P0.11)
rot3s2: D5.2 (A), SW58.2, SW58_2.S2

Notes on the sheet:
USB external connector
Mounting hole for PCB to plate
Battery connector. the battery will still charging if disconnected.
USB type C connection
Programmer connector
RProg = 1000/IBat IBat in amps
IBat 100mA 200mA 400mA 500mA 800mA
Reset Switch one under spacebar (for easy access) one in bottom
Unused PIN
RProg 10k 5k 2.5k 2k 1.25k

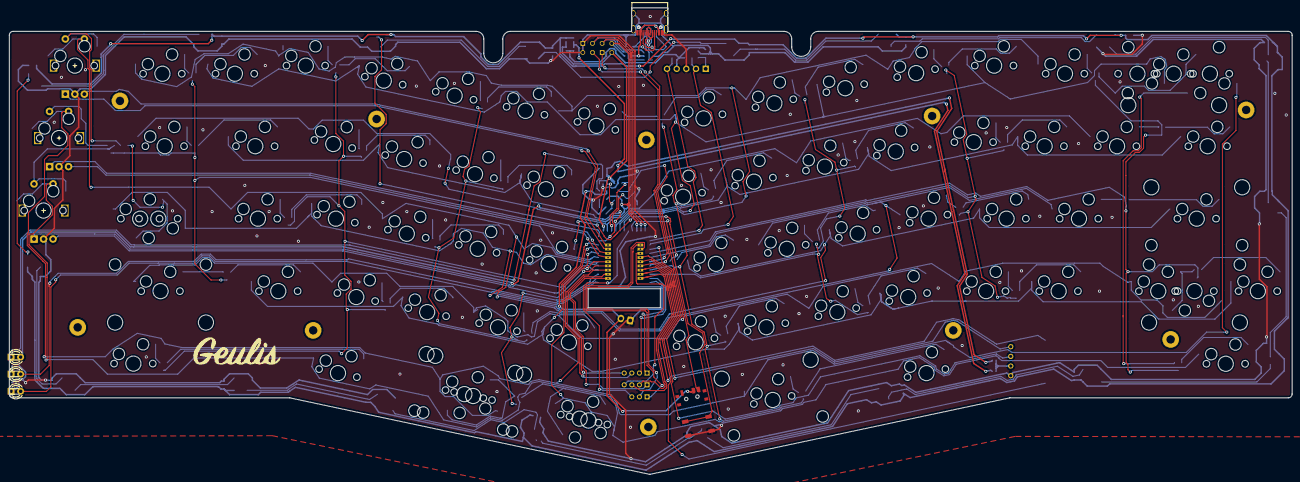
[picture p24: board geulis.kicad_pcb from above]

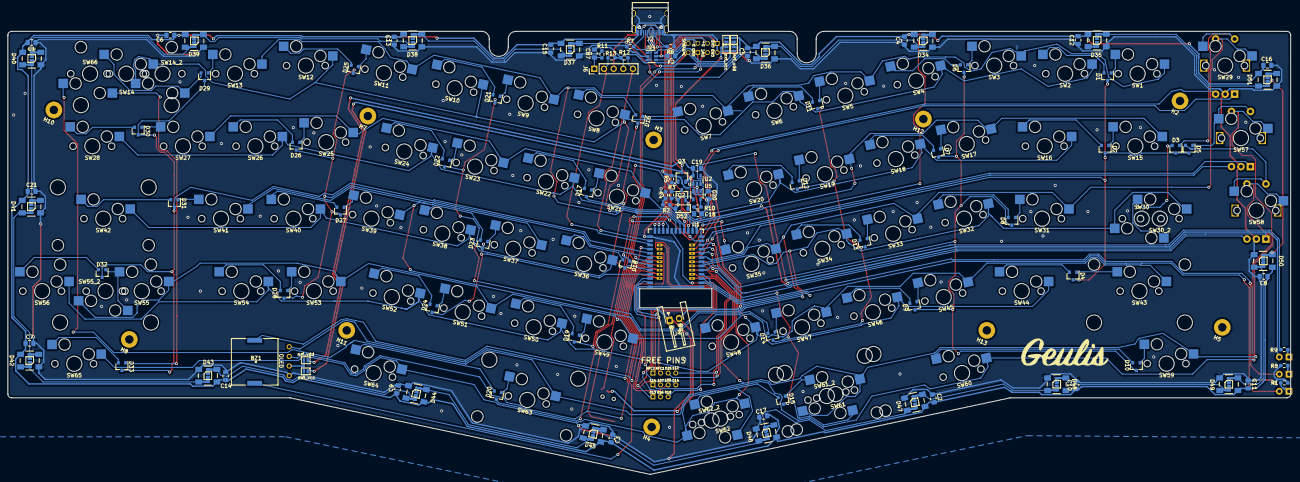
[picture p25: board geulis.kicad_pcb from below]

Board: 2 copper layers, 337.2 x 122.6 mm, 204 parts (114 on the bottom side), 154 nets.

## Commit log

2021-08-16 add other file
    [Cheshire full Acrylic_te4st.dwg, acrylic case outline.dwg, acrylic case outline.dxf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]
2024-10-26 organize file
    [Cheshire full Acrylic_te4st.dwg, acrylic case outline.dwg, acrylic case outline.dxf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]

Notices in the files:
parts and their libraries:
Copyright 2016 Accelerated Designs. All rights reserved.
